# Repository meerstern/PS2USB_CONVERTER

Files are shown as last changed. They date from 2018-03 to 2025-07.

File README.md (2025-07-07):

# PS/2 USB逆変換アダプタ
Description of PS/2USB_CONVERTER. 

## 概要
PS/2 USB逆変換アダプタはUSBキーボードをPS/2化する変換アダプタです。

標準ドライバで動作可能なUSBキーボードをPS/2キーボードとして使用できるように変換します。

[世の中で販売されている変換アダプタ][0]とは変換の向きが逆です。

[市販USBキーボード]<-USB->[PS/2 USB逆変換アダプタ]<-PS/2->[PC,ichigojam]

プログラミング専用こどもパソコンichigojamやサーバマシンなどのPS/2キーボードのみをサポートしている場合にPS/2 USB逆変換アダプタを使用して、USBキーボードをPS/2化します。

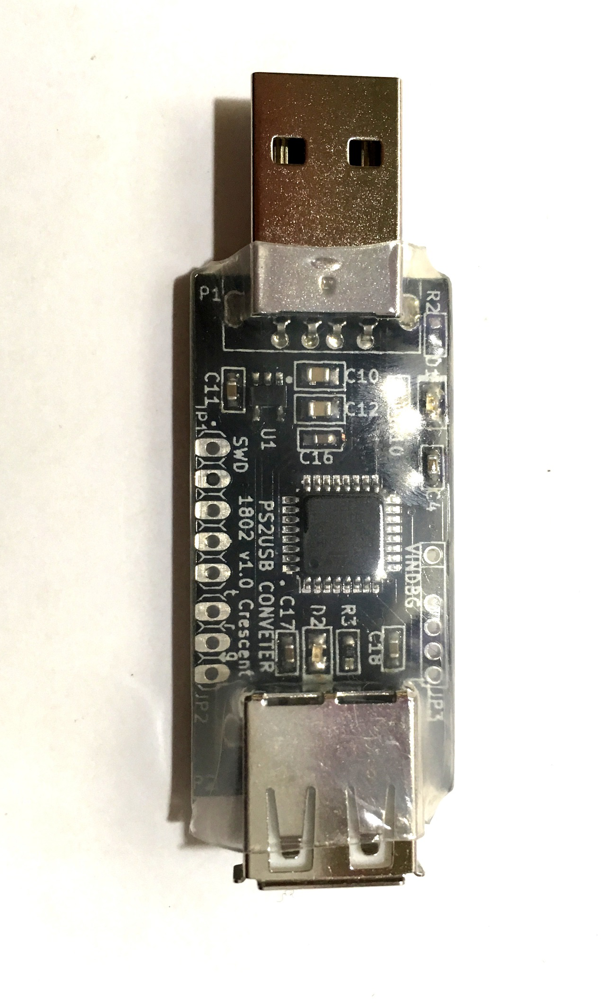
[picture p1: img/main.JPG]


## ichigojamで使用する場合
IchigoJam Tの場合はそのままキーボード用のUSB端子へPS/2 USB逆変換アダプタを接続してください。

IchigoJam Uと初代プリント基板の場合は同梱のUSB端子PS/2変換器を介して接続してください。

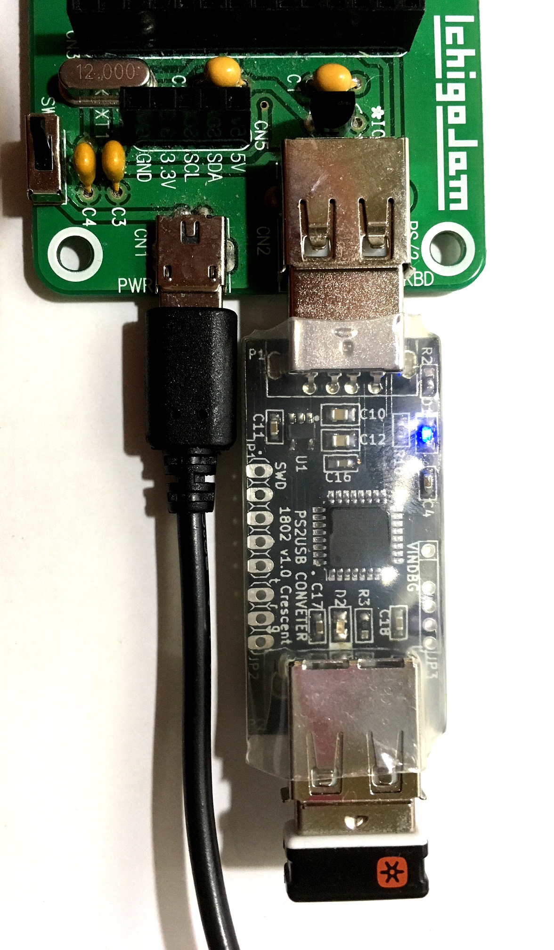
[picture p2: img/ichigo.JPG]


## 一般的なコンピュータで使用する場合
同梱のUSB端子PS/2変換器を介して接続してください。

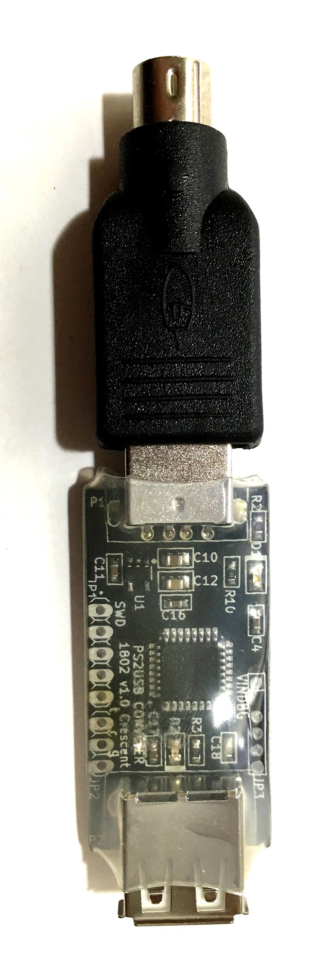
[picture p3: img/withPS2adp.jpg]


## 注意
  * USBキーボードをPS/2規格に変換しているため、すべての機器やキー入力を保証することはできません。  
  * すべての機器で対応することを保証できません。  
  * 音量調整やメールボタンといったキーボード固有の機能は使用できません。
  * Logicool製日本語、英語キーボードで動作確認しましたが、すべてのUSBキーボードの動作保証はできません。
  * 日本語、英語以外の言語のキーボードでは入力できないキーがある場合があります。
  * PS/2規格に変換しているため、キーレスポンスやキーリピート等の挙動がUSBで接続する場合と多少異なります。
  * PS/2キーボードとPS/2マウス兼用ポートに接続した場合、不具合が発生する場合はあります。変換ケーブル等でキーボードとマウスを分離して接続してください。
  * USBハブを介した接続には対応していません。直接キーボードのUSBを接続してください。
  * キーレスポンスが遅延する場合は電源投入時リセットに失敗している可能性があります。キーボードのUSBを接続した状態で再度、当該アダプタを抜き差ししてください。  
  * USBマウスとPS/2との変換に非公式で対応しています（コンポジットデバイスでなく、マウスデバイス単体として認識されるマウスのみ対応）    

## 告知
  * 使用ICの価格高騰、入手性を考慮し、STM32+VNC2-32ベースからPIC32ベースに移行済(22年3月)
  * 移行前の製品と移行後の製品で基本機能は同じですが、キーレスポンス等異なる場合があります  ご了承ください 
  * 上記写真は移行前につき、移行後の製品は若干基板実装部品等異なります  
  * 同梱のPS/2変換器の色や形状、LED色等の仕様を告知なしに変更する場合があります  
  
 ## 販売サイト
  * [スイッチサイエンス][1]
  * [家電のケンちゃん][2]
  * [PCN][3]
  
[0]: http://www.aitendo.com/product/16414 "*0"
[1]: https://www.switch-science.com/products/3785
[2]: https://www.kadenken.com/view/item/000000000767
[3]: https://hello002.stores.jp/items/5bce8ce05f78661b790000ce

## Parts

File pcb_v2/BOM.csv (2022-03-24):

Elecrow PN | Parts | Value | Package | QTY | Digikey/Mouser/Manufacturer Part | Remark/ Link
4040806A | D1,D2 | LED | LED_0603_1608Metric | 2
 | U1 | LD3985M33R | SOT-23-5 | 1 | 511-LD3985M33R
C23162 | R1,R7,R8 | 4.7k | R_0603_1608Metric | 3
C15850 | C1 | 10u | C_0805_2012Metric | 1
 | P1 | USB_PS2 | USBA | 1 | 490-UP2-AH-1-TH
 | F1 | Fuse | Fuse_0603_1608Metric | 1 | 650-FEMTOSMDC035F-02
C14663 | C18,C17,C16 | 0.1u | C_0603_1608Metric | 3
2014022A | C12,C10 | 2.2u | C_0603_1608Metric | 2
C57112 | C11 | 0.01u | C_0603_1608Metric | 1
C1644 | C7,C3 | 10p | C_0603_1608Metric | 2
 | P2 | USB_HOST | USBHOST | 1 | 530-SS-52100-001
C21190 | R2,R3 | 1k | R_0603_1608Metric | 2
 | X1 | 12MHz | FA238V | 1 | ECS-120-12-33-AGN-TR3
 | U2 | PIC32MX2XXFXXB(28-PIN) | SSOP-28_5.3x10.2mm_P0.65mm | 1 | 579-MX230F256B50I/SS

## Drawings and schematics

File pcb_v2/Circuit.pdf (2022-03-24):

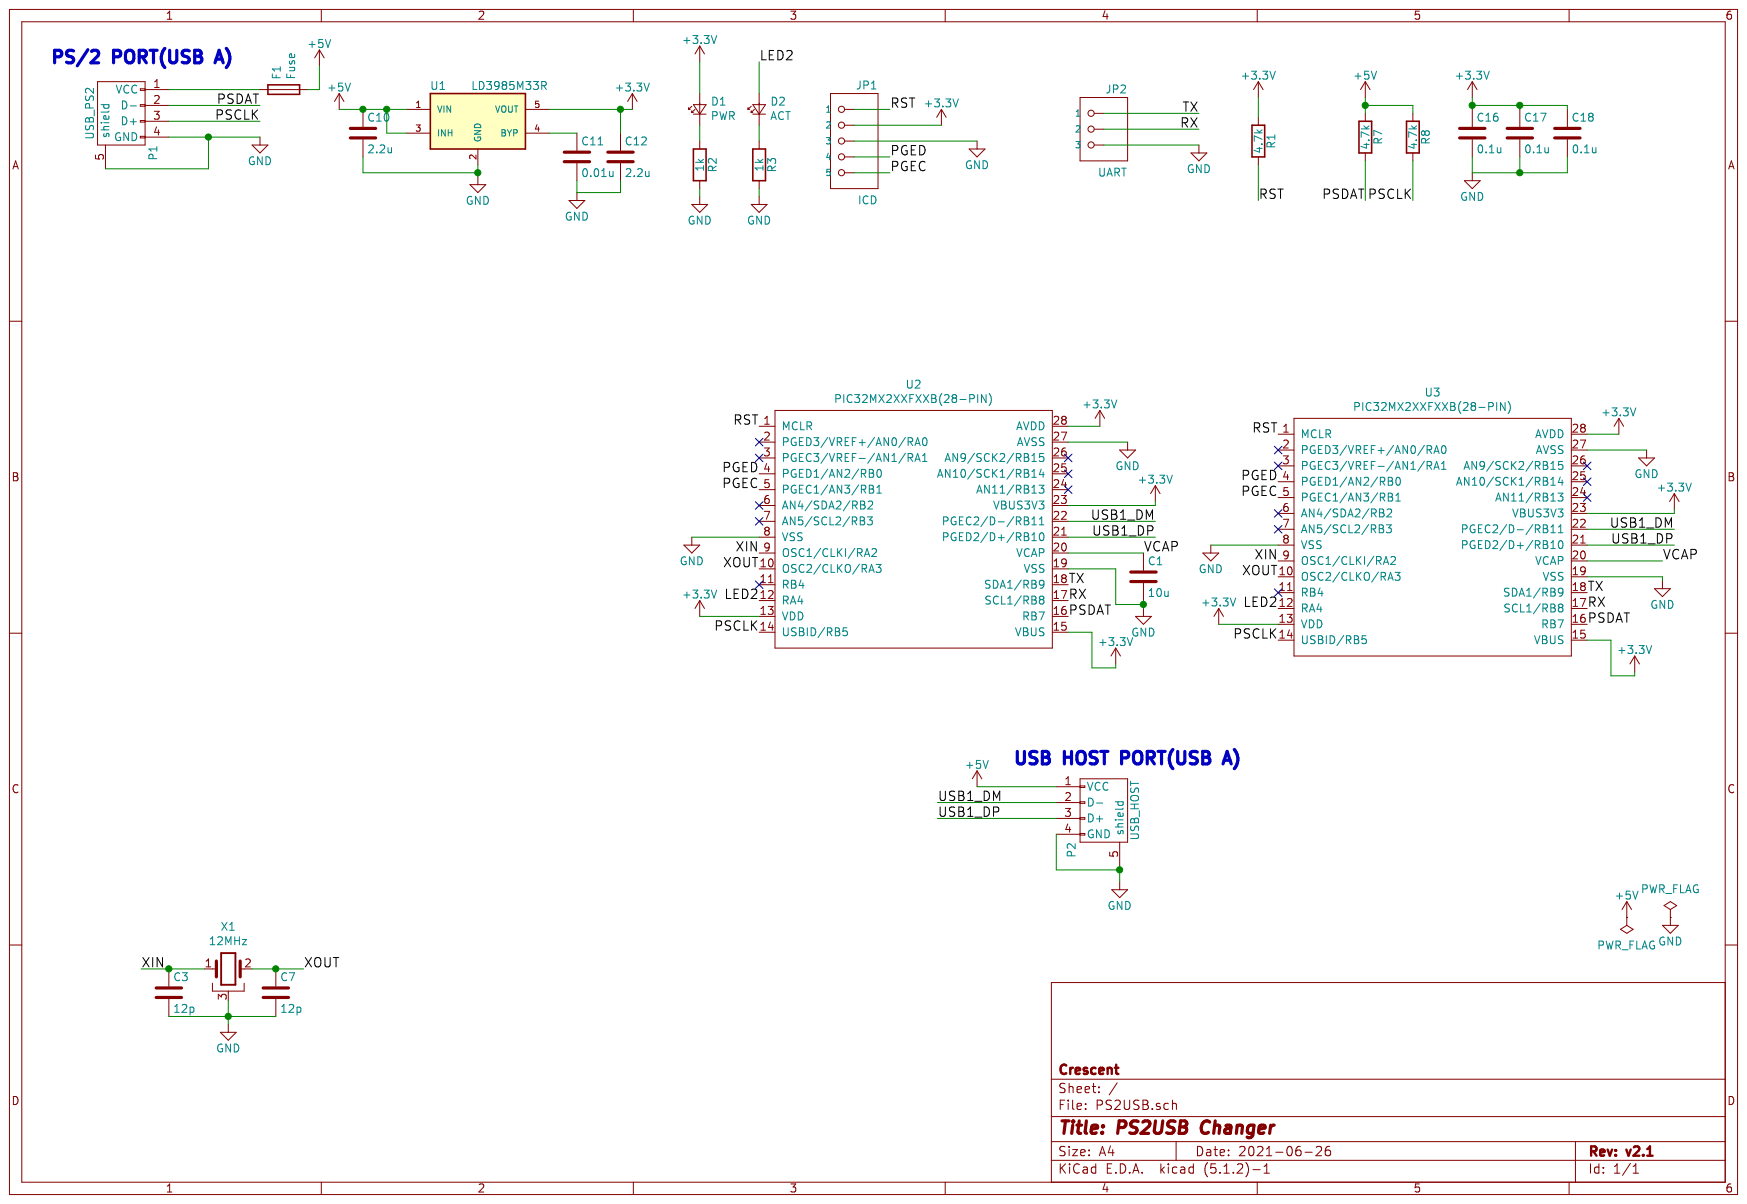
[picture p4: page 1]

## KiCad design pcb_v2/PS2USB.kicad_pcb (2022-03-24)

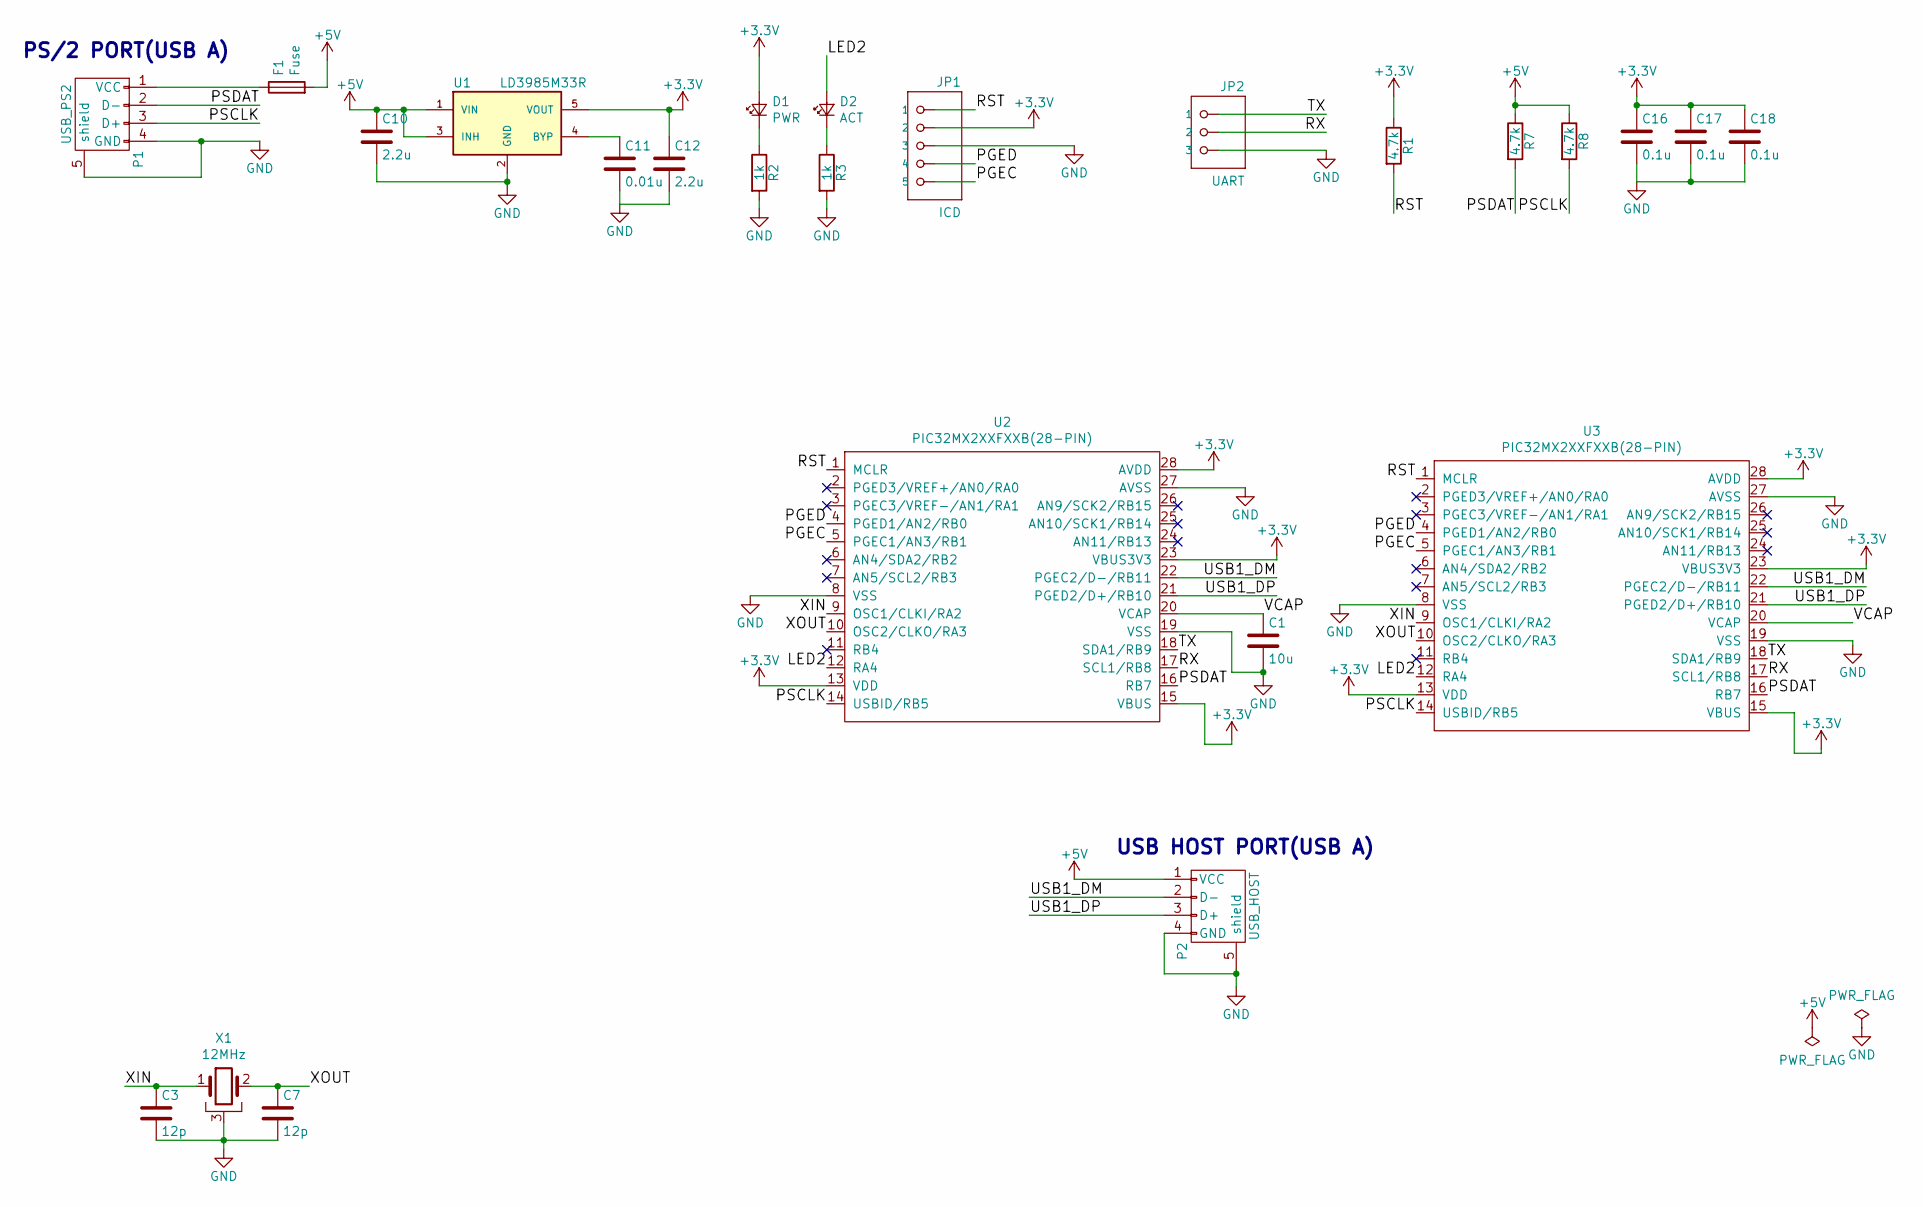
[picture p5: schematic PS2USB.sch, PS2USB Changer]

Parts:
C1: 10u; C_0805_2012Metric
C3, C7: 12p; C_0603_1608Metric
C10, C12: 2.2u; C_0603_1608Metric
C11: 0.01u; C_0603_1608Metric
C16, C17, C18: 0.1u; C_0603_1608Metric
D1: PWR; LED_0603_1608Metric
D2: ACT; LED_0603_1608Metric
F1: Fuse; Fuse_0603_1608Metric
JP1: ICD; PinHeader_1x05_P2.54mm_Vertical
JP2: UART; PinHeader_1x03_P2.54mm_Vertical
P1: USB_PS2; USBA
P2: USB_HOST; USBHOST
R1, R7, R8: 4.7k; R_0603_1608Metric
R2, R3: 1k; R_0603_1608Metric
U1: LD3985M33R; SOT-23-5
U2: PIC32MX2XXFXXB(28-PIN); SSOP-28_5.3x10.2mm_P0.65mm
U3: PIC32MX2XXFXXB(28-PIN); SOIC-28W_7.5x17.9mm_P1.27mm
X1: 12MHz; FA238V

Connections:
+3V3: C12.1, C16.1, C17.1, C18.1, D1.2 (A), JP1.2, R1.1, U1.5 (VOUT), U2.13 (VDD), U2.15 (VBUS), U2.23 (VBUS3V3), U2.28 (AVDD), U3.13 (VDD), U3.15 (VBUS), U3.23 (VBUS3V3), U3.28 (AVDD)
+5V: C10.1, F1.2, P2.1 (VCC), R7.1, R8.1, U1.1 (VIN), U1.3 (INH)
/LED2: D2.2 (A), U2.12 (RA4), U3.12 (RA4)
/PGEC: JP1.5, U2.5 (PGEC1/AN3/RB1), U3.5 (PGEC1/AN3/RB1)
/PGED: JP1.4, U2.4 (PGED1/AN2/RB0), U3.4 (PGED1/AN2/RB0)
/PSCLK: P1.3 (D+), R8.2, U2.14 (USBID/RB5), U3.14 (USBID/RB5)
/PSDAT: P1.2 (D-), R7.2, U2.16 (RB7), U3.16 (RB7)
/RST: JP1.1, R1.2, U2.1 (MCLR), U3.1 (MCLR)
/RX: JP2.2, U2.17 (SCL1/RB8), U3.17 (SCL1/RB8)
/TX: JP2.1, U2.18 (SDA1/RB9), U3.18 (SDA1/RB9)
/USB1_DM: P2.2 (D-), U2.22 (PGEC2/D-/RB11), U3.22 (PGEC2/D-/RB11)
/USB1_DP: P2.3 (D+), U2.21 (PGED2/D+/RB10), U3.21 (PGED2/D+/RB10)
/VCAP: C1.1, U2.20 (VCAP), U3.20 (VCAP)
/XIN: C3.1, U2.9 (OSC1/CLKI/RA2), U3.9 (OSC1/CLKI/RA2), X1.1
/XOUT: C7.1, U2.10 (OSC2/CLKO/RA3), U3.10 (OSC2/CLKO/RA3), X1.2
GND: C1.2, C3.2, C7.2, C10.2, C11.2, C12.2, C16.2, C17.2, C18.2, JP1.3, JP2.3, P1.4 (GND), P1.5 (shield), P2.4 (GND), P2.5 (shield), R2.2, R3.2, U1.2 (GND), U2.8 (VSS), U2.19 (VSS), U2.27 (AVSS), U3.8 (VSS), U3.19 (VSS), U3.27 (AVSS), X1.3
unnamed: C11.1, U1.4 (BYP)
unnamed: D1.1 (K), R2.1
unnamed: D2.1 (K), R3.1
unnamed: F1.1, P1.1 (VCC)

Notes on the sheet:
PS/2 PORT(USB A)
USB HOST PORT(USB A)

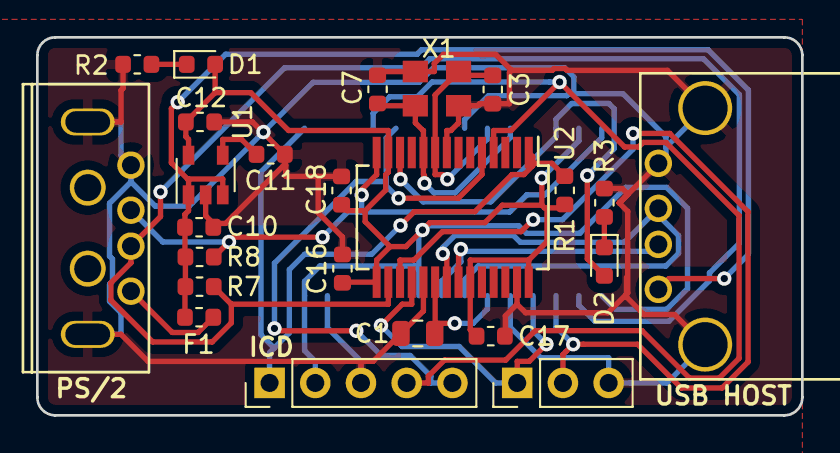
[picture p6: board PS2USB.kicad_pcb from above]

Board: 2 copper layers, 42.5 x 21.0 mm, 25 parts (1 on the bottom side), 20 nets.

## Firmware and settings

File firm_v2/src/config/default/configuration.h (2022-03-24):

/*******************************************************************************
  System Configuration Header

  File Name:
    configuration.h

  Summary:
    Build-time configuration header for the system defined by this project.

  Description:
    An MPLAB Project may have multiple configurations.  This file defines the
    build-time options for a single configuration.

  Remarks:
    This configuration header must not define any prototypes or data
    definitions (or include any files that do).  It only provides macro
    definitions for build-time configuration options

*******************************************************************************/

// DOM-IGNORE-BEGIN
/*******************************************************************************
* Copyright (C) 2018 Microchip Technology Inc. and its subsidiaries.
*
* Subject to your compliance with these terms, you may use Microchip software
* and any derivatives exclusively with Microchip products. It is your
* responsibility to comply with third party license terms applicable to your
* use of third party software (including open source software) that may
* accompany Microchip software.
*
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
* IN NO EVENT WILL MICROCHIP BE LIABLE FOR ANY INDIRECT, SPECIAL, PUNITIVE,
* INCIDENTAL OR CONSEQUENTIAL LOSS, DAMAGE, COST OR EXPENSE OF ANY KIND
* WHATSOEVER RELATED TO THE SOFTWARE, HOWEVER CAUSED, EVEN IF MICROCHIP HAS
* BEEN ADVISED OF THE POSSIBILITY OR THE DAMAGES ARE FORESEEABLE. TO THE
* FULLEST EXTENT ALLOWED BY LAW, MICROCHIP'S TOTAL LIABILITY ON ALL CLAIMS IN
* ANY WAY RELATED TO THIS SOFTWARE WILL NOT EXCEED THE AMOUNT OF FEES, IF ANY,
* THAT YOU HAVE PAID DIRECTLY TO MICROCHIP FOR THIS SOFTWARE.
*******************************************************************************/
// DOM-IGNORE-END

#ifndef CONFIGURATION_H
#define CONFIGURATION_H

// *****************************************************************************
// *****************************************************************************
// Section: Included Files
// *****************************************************************************
// *****************************************************************************
/*  This section Includes other configuration headers necessary to completely
    define this configuration.
*/

#include "user.h"
#include "toolchain_specifics.h"

// DOM-IGNORE-BEGIN
#ifdef __cplusplus  // Provide C++ Compatibility

extern "C" {

#endif
// DOM-IGNORE-END

// *****************************************************************************
// *****************************************************************************
// Section: System Configuration
// *****************************************************************************
// *****************************************************************************



// *****************************************************************************
// *****************************************************************************
// Section: System Service Configuration
// *****************************************************************************
// *****************************************************************************
#define SYS_CONSOLE_DEVICE_MAX_INSTANCES   			1
#define SYS_CONSOLE_UART_MAX_INSTANCES 	   			1
#define SYS_CONSOLE_USB_CDC_MAX_INSTANCES 	   		0
#define SYS_CONSOLE_PRINT_BUFFER_SIZE        		256


#define SYS_CONSOLE_INDEX_0                       0





//#define SYS_DEBUG_ENABLE
#define SYS_DEBUG_GLOBAL_ERROR_LEVEL      SYS_ERROR_DEBUG// SYS_ERROR_FATAL//SYS_ERROR_DEBUG
#define SYS_DEBUG_BUFFER_DMA_READY
#define SYS_DEBUG_USE_CONSOLE


/* TIME System Service Configuration Options */
#define SYS_TIME_INDEX_0                            (0)
#define SYS_TIME_MAX_TIMERS                         (5)
#define SYS_TIME_HW_COUNTER_WIDTH                   (32)
#define SYS_TIME_HW_COUNTER_PERIOD                  (4294967295U)
#define SYS_TIME_HW_COUNTER_HALF_PERIOD             (SYS_TIME_HW_COUNTER_PERIOD>>1)
#define SYS_TIME_CPU_CLOCK_FREQUENCY                (40000000)
#define SYS_TIME_COMPARE_UPDATE_EXECUTION_CYCLES    (460)



// *****************************************************************************
// *****************************************************************************
// Section: Driver Configuration
// *****************************************************************************
// *****************************************************************************
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

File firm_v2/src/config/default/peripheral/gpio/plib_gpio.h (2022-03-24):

/*******************************************************************************
  GPIO PLIB

  Company:
    Microchip Technology Inc.

  File Name:
    plib_gpio.h

  Summary:
    GPIO PLIB Header File

  Description:
    This library provides an interface to control and interact with Parallel
    Input/Output controller (GPIO) module.

*******************************************************************************/

/*******************************************************************************
* Copyright (C) 2019 Microchip Technology Inc. and its subsidiaries.
*
* Subject to your compliance with these terms, you may use Microchip software
* and any derivatives exclusively with Microchip products. It is your
* responsibility to comply with third party license terms applicable to your
* use of third party software (including open source software) that may
* accompany Microchip software.
*
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
* IN NO EVENT WILL MICROCHIP BE LIABLE FOR ANY INDIRECT, SPECIAL, PUNITIVE,
* INCIDENTAL OR CONSEQUENTIAL LOSS, DAMAGE, COST OR EXPENSE OF ANY KIND
* WHATSOEVER RELATED TO THE SOFTWARE, HOWEVER CAUSED, EVEN IF MICROCHIP HAS
* BEEN ADVISED OF THE POSSIBILITY OR THE DAMAGES ARE FORESEEABLE. TO THE
* FULLEST EXTENT ALLOWED BY LAW, MICROCHIP'S TOTAL LIABILITY ON ALL CLAIMS IN
* ANY WAY RELATED TO THIS SOFTWARE WILL NOT EXCEED THE AMOUNT OF FEES, IF ANY,
* THAT YOU HAVE PAID DIRECTLY TO MICROCHIP FOR THIS SOFTWARE.
*******************************************************************************/

#ifndef PLIB_GPIO_H
#define PLIB_GPIO_H

#include <device.h>
#include <stdint.h>
#include <stdbool.h>
#include <stddef.h>

// DOM-IGNORE-BEGIN
#ifdef __cplusplus  // Provide C++ Compatibility

    extern "C" {

#endif
// DOM-IGNORE-END

// *****************************************************************************
// *****************************************************************************
// Section: Data types and constants
// *****************************************************************************
// *****************************************************************************


/*** Macros for LED pin ***/
#define LED_Set()               (LATASET = (1<<4))
#define LED_Clear()             (LATACLR = (1<<4))
#define LED_Toggle()            (LATAINV= (1<<4))
#define LED_OutputEnable()      (TRISACLR = (1<<4))
#define LED_InputEnable()       (TRISASET = (1<<4))
#define LED_Get()               ((PORTA >> 4) & 0x1)
#define LED_PIN                  GPIO_PIN_RA4

/*** Macros for PS2CLK pin ***/
#define PS2CLK_Set()               (LATBSET = (1<<5))
#define PS2CLK_Clear()             (LATBCLR = (1<<5))
#define PS2CLK_Toggle()            (LATBINV= (1<<5))
#define PS2CLK_OutputEnable()      (TRISBCLR = (1<<5))
#define PS2CLK_InputEnable()       (TRISBSET = (1<<5))
#define PS2CLK_Get()               ((PORTB >> 5) & 0x1)
#define PS2CLK_PIN                  GPIO_PIN_RB5

/*** Macros for PS2DAT pin ***/
#define PS2DAT_Set()               (LATBSET = (1<<7))
#define PS2DAT_Clear()             (LATBCLR = (1<<7))
#define PS2DAT_Toggle()            (LATBINV= (1<<7))
#define PS2DAT_OutputEnable()      (TRISBCLR = (1<<7))
#define PS2DAT_InputEnable()       (TRISBSET = (1<<7))
#define PS2DAT_Get()               ((PORTB >> 7) & 0x1)
#define PS2DAT_PIN                  GPIO_PIN_RB7

/*** Macros for TX pin ***/
#define TX_Get()               ((PORTB >> 9) & 0x1)
#define TX_PIN                  GPIO_PIN_RB9


// *****************************************************************************
/* GPIO Port

  Summary:
    Identifies the available GPIO Ports.

  Description:
    This enumeration identifies the available GPIO Ports.

  Remarks:
    The caller should not rely on the specific numbers assigned to any of
    these values as they may change from one processor to the next.

    Not all ports are available on all devices.  Refer to the specific
    device data sheet to determine which ports are supported.
*/

typedef enum
{
    GPIO_PORT_A = 0,
    GPIO_PORT_B = 1,
} GPIO_PORT;

// *****************************************************************************
/* GPIO Port Pins

  Summary:
    Identifies the available GPIO port pins.

  Description:
    This enumeration identifies the available GPIO port pins.

  Remarks:
    The caller should not rely on the specific numbers assigned to any of
    these values as they may change from one processor to the next.

    Not all pins are available on all devices.  Refer to the specific
    device data sheet to determine which pins are supported.
*/
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
